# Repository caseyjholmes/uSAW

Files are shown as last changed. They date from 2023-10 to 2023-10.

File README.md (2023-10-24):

# μSAW
TL074/Matched 3904/PSI powered SMD 2HP sized analog Voltage Controlled Saw Oscillator for Eurorack by Holmes Modular

View module on Modular Grid https://www.modulargrid.net/e/other-unknown-holmes-modular-%CE%BCsaw

This module is currently in the testing phase.

The BOM may also need an update. 

Panel and PCB have been tested 10/23/23. I'm testing BOM components and tuning now - Check back in a couple days will probably be done! 
-Casey

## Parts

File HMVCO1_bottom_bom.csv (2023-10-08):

Comment | Designator | Footprint | LCSC Part #
*** | R9 | R0603
.1uf | C6 | C0603K
1n | C1 | C0603K
1n4148W-HE3-18 | D1 | SOD-123
2k | TRIM1 TRIM2 | TRIMPOT-SMD-TC33X
10k | R1 R14 | R0603
10u | C3 | C0603K
22uf | C4 C5 | PANASONIC_C
100k | R4 R5 | R0603
DMMT3904W-7-F | Q1 | SOT65P210X100-6N
MB1S | B1 | SOIC-4
TL074 | U1 | TSSOP14

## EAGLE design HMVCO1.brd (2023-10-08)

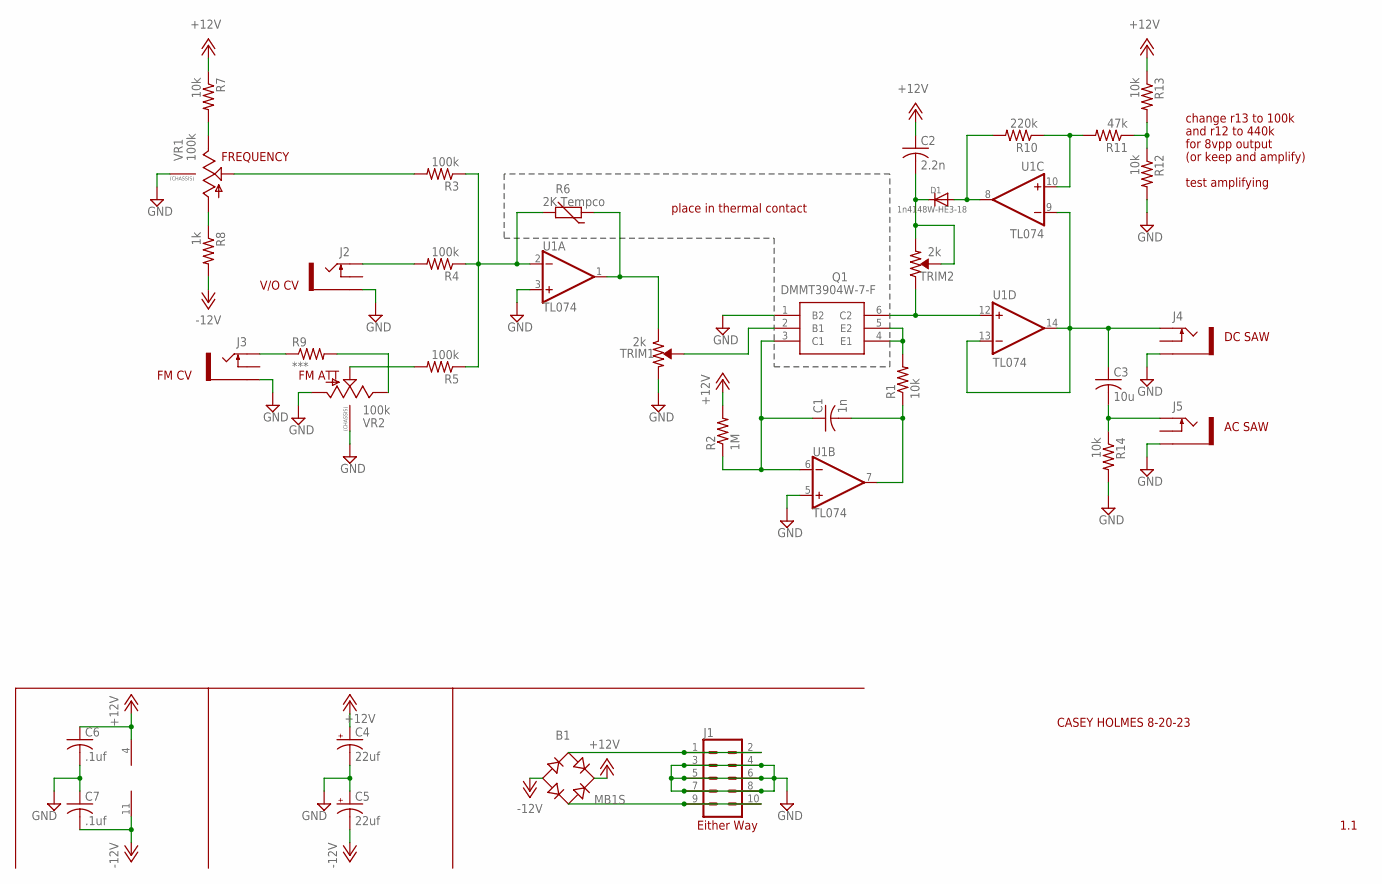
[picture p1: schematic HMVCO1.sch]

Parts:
B1: MB1S; SOIC-4
C1: 1n; C0603K
C2: 2.2n; C0603K
C3: 10u; C0603K
C4, C5: 22uf; PANASONIC_C
C6, C7: .1uf; C0603K
D1: 1n4148W-HE3-18; SOD-123
J1: CONN_05X2PTH; 2X5
J2, J3, J4, J5: THONKICONNNEW; WQP-PJ301M-12_JACK
Q1: DMMT3904W-7-F; SOT65P210X100-6N
R1, R7, R12, R13, R14: 10k; R0603
R2: 1M; R0603
R3, R4, R5: 100k; R0603
R6: 2K Tempco; R-5
R8: 1k; R0603
R9: ***; R0603
R10: 220k; R0603
R11: 47k; R0603
TRIM1, TRIM2: 2k; TRIMPOT-SMD-TC33X
U1: TL074; TSSOP14
VR1, VR2: 100k; 9MM_SNAP-IN_POT

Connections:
+12V: B1.+, C2.1, C4.+, C6.1, R2.2, R7.1, R13.1, U1.4 (V+)
-12V: B1.-, C5.-, C7.2, R8.2, U1.11 (V-)
GND: C4.-, C5.+, C6.2, C7.1, J1.3, J1.4, J1.5, J1.6, J1.7, J1.8, J2.P$3_SLEEVE (SLEEVE), J3.P$3_SLEEVE (SLEEVE), J4.P$3_SLEEVE (SLEEVE), J5.P$3_SLEEVE (SLEEVE), Q1.1 (B2), R12.2, R14.2, TRIM1.3 (CCW), U1.3 (+IN), U1.5 (+IN), VR1.CHASSIS1, VR1.CHASSIS2, VR2.1 (A), VR2.CHASSIS1, VR2.CHASSIS2
unnamed: Q1.4 (E1), Q1.5 (E2), R1.2
unnamed: Q1.2 (B1), TRIM1.2 (WIPER)
unnamed: Q1.6 (C2), TRIM2.1 (CW), U1.12 (+IN)
unnamed: R6.1, TRIM1.1 (CW), U1.1 (OUT)
unnamed: C1.1, Q1.3 (C1), R2.1, U1.6 (-IN)
unnamed: R3.1, R4.1, R5.1, R6.2, U1.2 (-IN)
unnamed: C1.2, R1.1, U1.7 (OUT)
unnamed: J2.P$1_TIP (TIP), R4.2
unnamed: R3.2, VR1.2 (S)
unnamed: R8.1, VR1.1 (A)
unnamed: R7.2, VR1.3 (E)
unnamed: R9.2, VR2.3 (E)
unnamed: R5.2, VR2.2 (S)
unnamed: J3.P$1_TIP (TIP), R9.1
unnamed: C3.1, J4.P$1_TIP (TIP), U1.9 (-IN), U1.13 (-IN), U1.14 (OUT)
unnamed: C2.2, D1.C, TRIM2.2 (WIPER), TRIM2.3 (CCW)
unnamed: D1.A, R10.2, U1.8 (OUT)
unnamed: R10.1, R11.2, U1.10 (+IN)
unnamed: R11.1, R12.1, R13.2
unnamed: C3.2, J5.P$1_TIP (TIP), R14.1
unnamed: B1.~2 (AC2), J1.9, J1.10
unnamed: B1.~1 (AC1), J1.1, J1.2

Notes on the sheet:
V/O CV
FM CV
FM ATT
FREQUENCY
place in thermal contact
DC SAW
AC SAW
Either Way
CASEY HOLMES 8-20-23
1.1
change r13 to 100k
and r12 to 440k
for 8vpp output
(or keep and amplify)
test amplifying

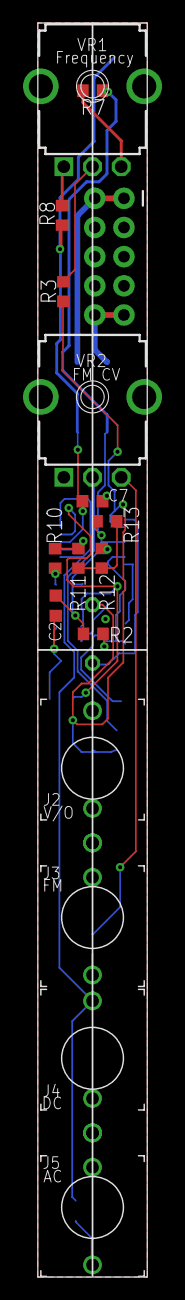
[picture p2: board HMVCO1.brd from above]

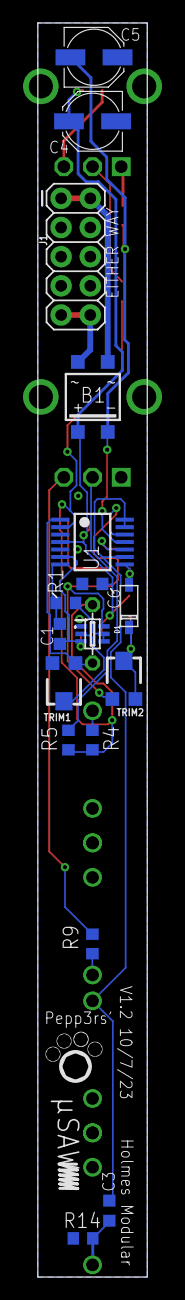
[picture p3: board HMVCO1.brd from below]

Board: 2 copper layers, 9.5 x 109.2 mm, 34 parts (18 on the bottom side), 25 nets.

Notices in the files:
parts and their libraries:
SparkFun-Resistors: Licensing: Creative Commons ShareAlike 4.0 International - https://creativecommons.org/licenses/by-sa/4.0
